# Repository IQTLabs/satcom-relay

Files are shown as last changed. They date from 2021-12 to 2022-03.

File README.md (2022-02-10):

# Satellite Communication Relay

## About

A SATCOM platform for relaying messages in remote locations.  This project provides a standard interface for messages to be relayed over a Satcom link.  Initially, this is  using the RockBlock Iridium 9603 satellite modem, but the system is designed to be able to handle any other satcom system designed for small burst data transmissions.

## System Design

### Architecture Diagram

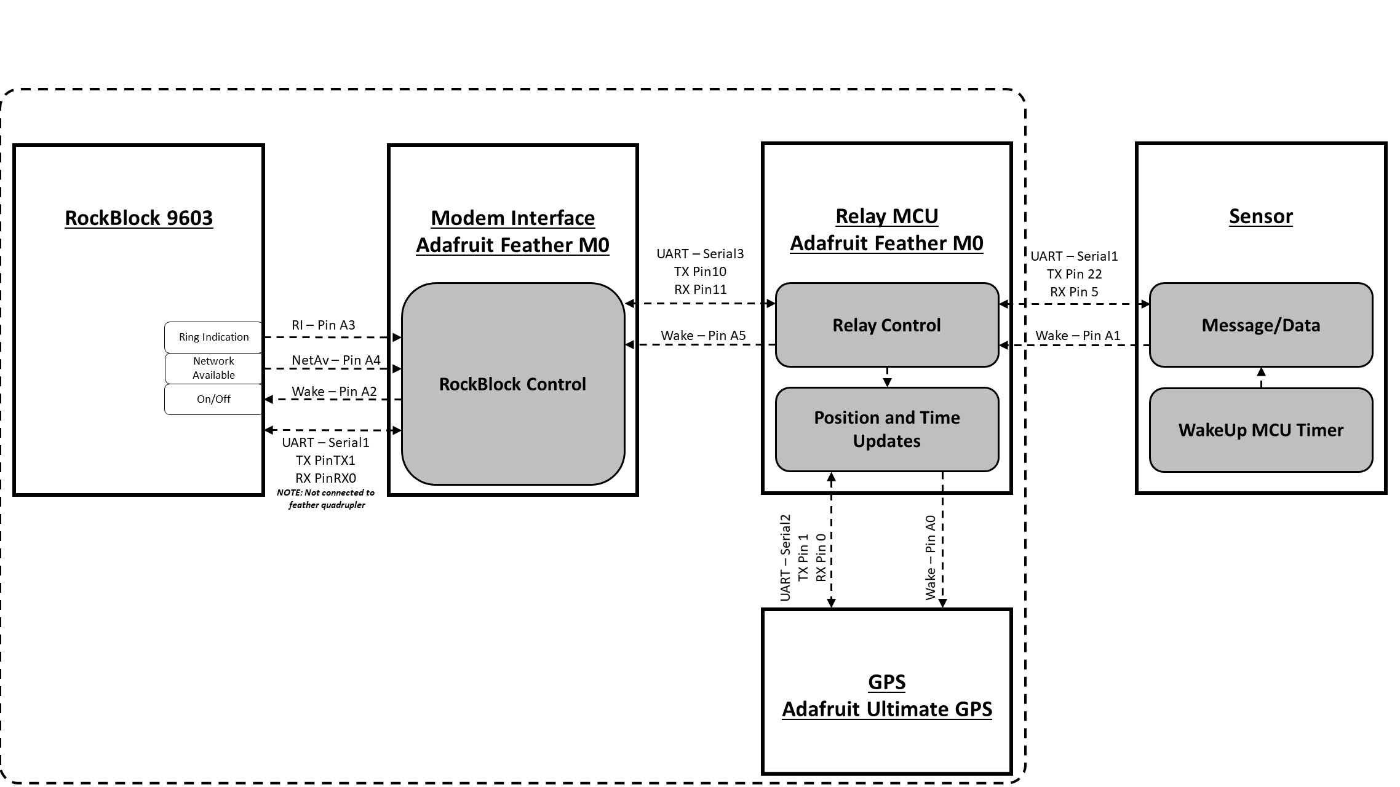
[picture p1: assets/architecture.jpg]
architecture


### Relay MCU

- Adafruit Feather M0 Basic [(diagram)](https://cdn-learn.adafruit.com/assets/assets/000/046/244/original/adafruit_products_Feather_M0_Basic_Proto_v2.2-1.png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)
    - The M0 was chosen as the Relay MCU because of its [6 SERCOM interfaces](https://learn.adafruit.com/using-atsamd21-sercom-to-add-more-spi-i2c-serial-ports/creating-a-new-serial).

### Iridium Modem Interface MCU
- Adafruit Feather M0 Adalogger [(diagram)](https://cdn-learn.adafruit.com/assets/assets/000/107/293/original/adafruit_products_Adafruit_Feather_M0_Adalogger_Pinout.png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)
- Firmware: https://github.com/IQTLabs/satcom-modem-interface

### Wiring Diagram

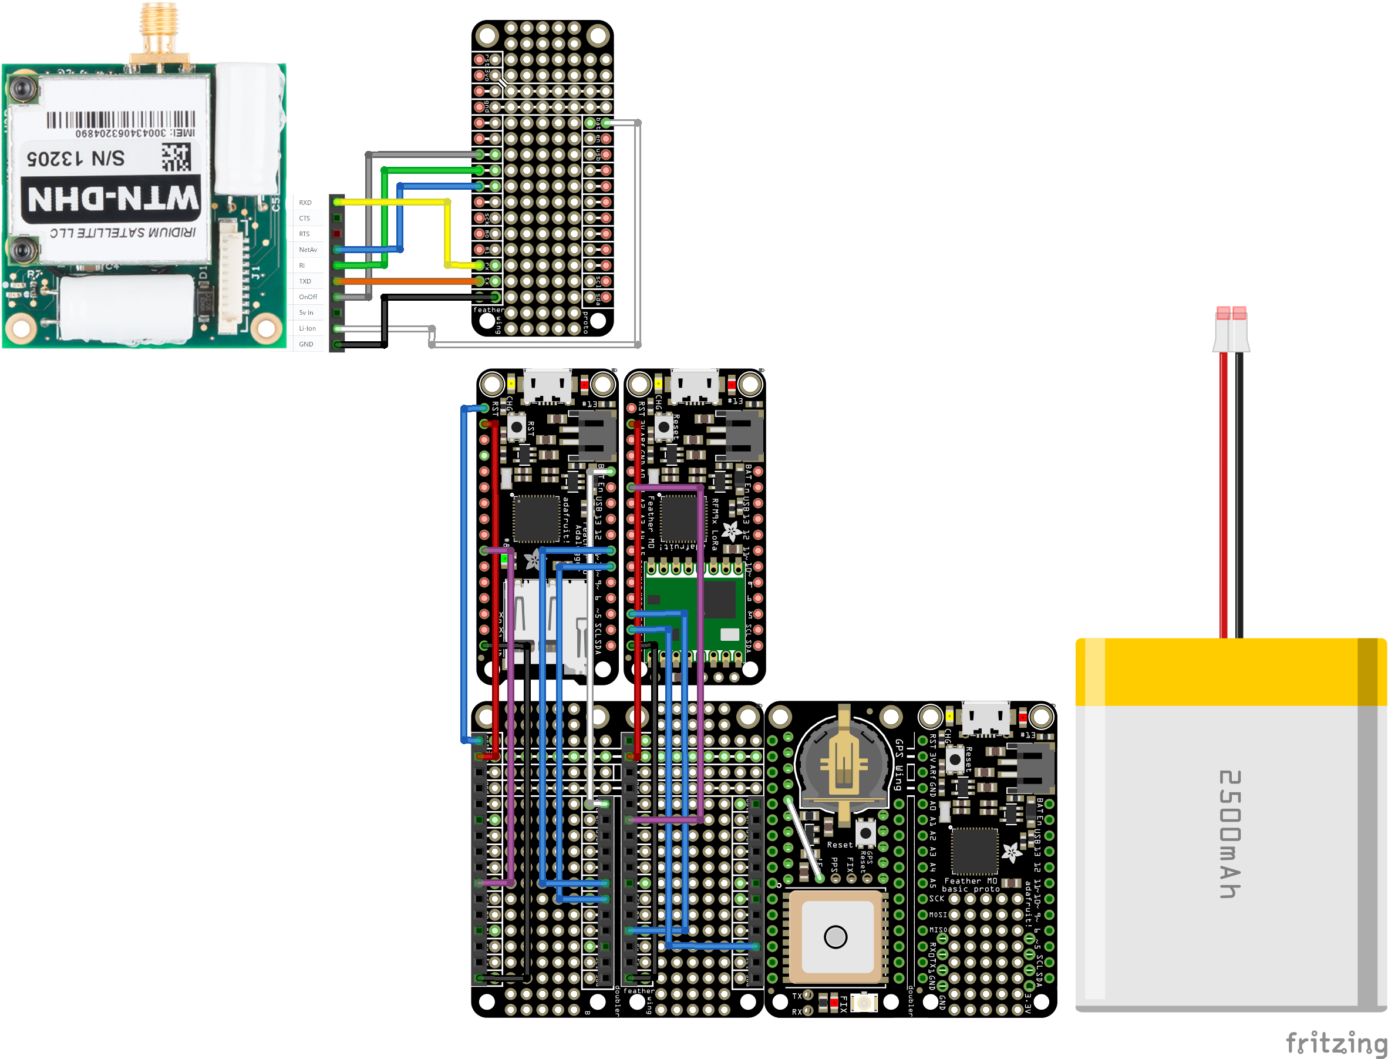
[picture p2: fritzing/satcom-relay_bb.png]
fritzing


*Note on connecting AdaLogger Feather and LoRa Feather: Only pins with indicated wires should be connected to quadrupler. All others should be removed or folded out of the way.

### Arduino Setup / Flashing

1. Install Arduinu IDE
2. Install Arduino **Adafruit M0 SAMD21** Board
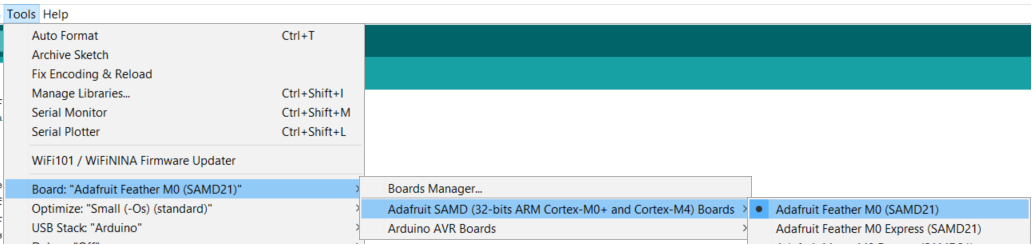
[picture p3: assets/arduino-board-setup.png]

3. Install Arduino Libraries
    - **Adafruit GPS Library** by Adafruit
    - **IridiumSBDi2c** by SparkFun Electronics [(datasheet)](https://docs.rockblock.rock7.com/docs/connectors)
    - **ArduinoJson** by Benoit Blanchon
4. Clone / download repository, open .ino file, and flash to MCU
    - Relay MCU
        - satcom-relay.ino
        - **Adafruit Feather M0**
    - Modem Interface MCU
        - satcom-modem-interface.ino*
        - **Adafruit Feather M0 AdaLogger**

### Hardware Assembly



### Bill of Materials
| Short Name | Product Name | Price | Link |
| --- | --- | ----- | ---- |
| MCU | Feather M0 Basic Proto | $19.95 | https://www.adafruit.com/product/2772 |
| GPS | Ultimate GPS FeatherWing | $24.95 | https://www.adafruit.com/product/3133 |
| SATCOM Interface MCU | Feather M0 Adalogger | $19.95 | https://www.adafruit.com/product/2796 |
| Stacking Headers | Stacking Headers for Feather - 12-pin and 16-pin female headers | $1.25 | https://www.adafruit.com/product/2830 |
| SATCOM Modem | RockBlock 9603N | $249.95 | https://www.adafruit.com/product/4521 |
| PCB-A | Feather Quad Side-By-Side | $9.95 | https://www.adafruit.com/product/4254 |
| PCB-B | RockBlock to Feather Adapter | --- | [Design Files](./electrical/IridiumPCB) |
| Battery | Lithium Ion Battery Pack - 3.7V 6600mAh | $24.50 |  https://www.adafruit.com/product/353 |
| GPS Battery | CR1220 Coin Cell Battery | $0.95 | https://www.adafruit.com/product/380 |
| Sensor FeatherWing | FeatherWing Proto | $4.95 | https://www.adafruit.com/product/2884 |
| Micro SD Card | Micro SD Card | --- | --- |
| Dry Box Case | SE 56 Micro | $26.00 | https://evergreencases.com/ |
| Dry Box Screws | Rounded Head Thread-Forming Screws for Brittle Plastic, 18-8 Stainless Steel, Number 4 Size, 3/8" Long | --- | https://www.mcmaster.com/97349A100/ |
| 3D Printed Case Chassis | SE56-chassis.STL | --- | [SE56-chassis.STL](./hardware/SE56-chassis.STL) |
| Threaded Inserts | Tapered Heat-Set Inserts for Plastic Brass, M2.5 x 0.45 mm Thread Size, 3.4 mm Installed Length | --- | https://www.mcmaster.com/94180A321/ |
| Mounting Screws | Button Head Hex Drive Screw Passivated 18-8 Stainless Steel, M2.5 x 0.45 mm Thread, 4mm Long | --- | https://www.mcmaster.com/92095A456/ |
| Mounting Screws | Button Head Hex Drive Screw 18-8 Stainless Steel, M2.5 x 0.45 Thread Size, 20mm Long | --- | https://www.mcmaster.com/92095A115/ |

## Operations

The M0 uses SERCOM2 (RX pin 5 and TX pin 22) to listen for JSON messages from other devices. These messages then get additional keys added (`uptime_ms` and `version`) and then logged out the console.

The M0 will automatically go to sleep after `AWAKE_INTERVAL` (1 minute) if the interrupt pin (A1) hasn't been toggled. Every time the interrupt pin is toggled the `awakeTimer` is reset and the count towards `AWAKE_INTERVAL` starts over. When in sleep mode, toggling the interrupt pin will wake up the M0 again.

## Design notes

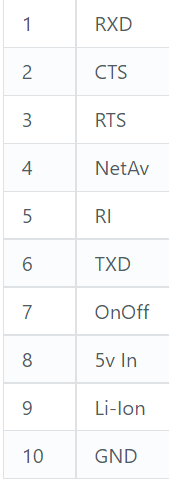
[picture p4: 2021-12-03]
fritzing/rockblock-9603-pinout.png

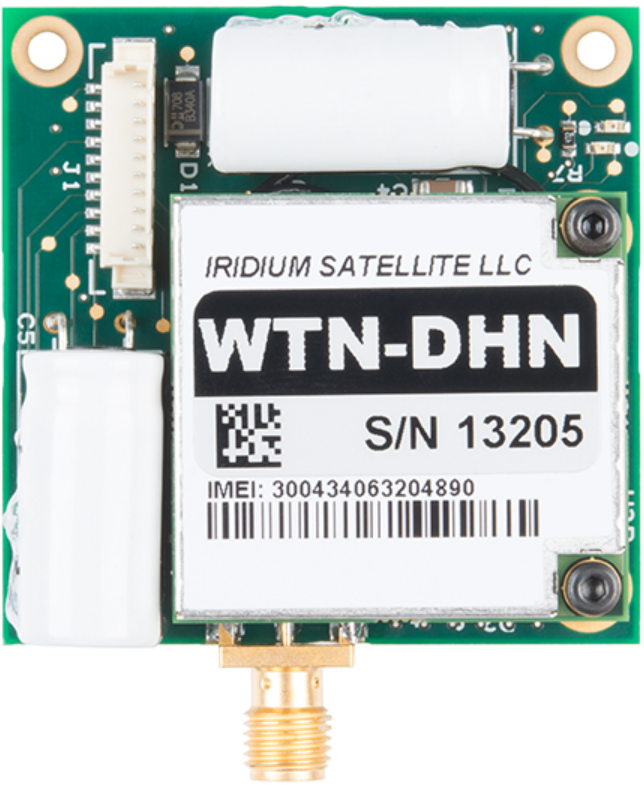
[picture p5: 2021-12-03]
fritzing/rockblock-9603.png

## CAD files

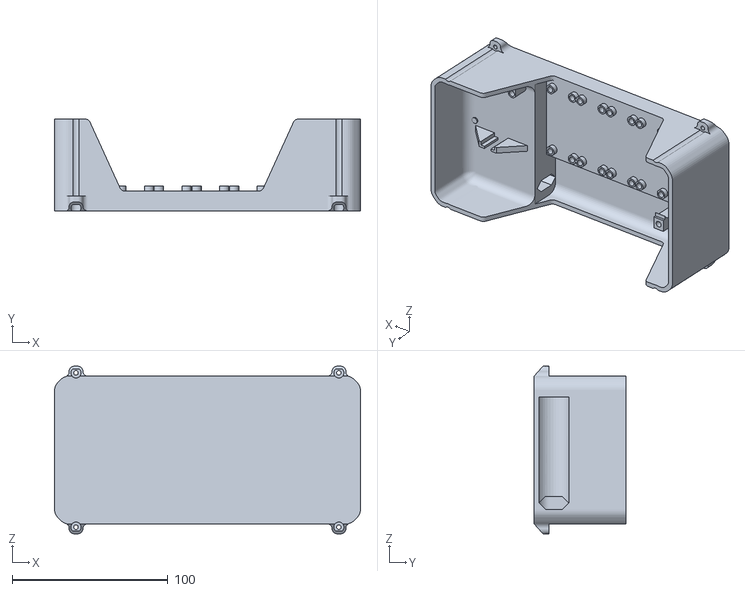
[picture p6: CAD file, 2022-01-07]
hardware/SE56-chassis.STL
196.5 x 58.9 x 107.6

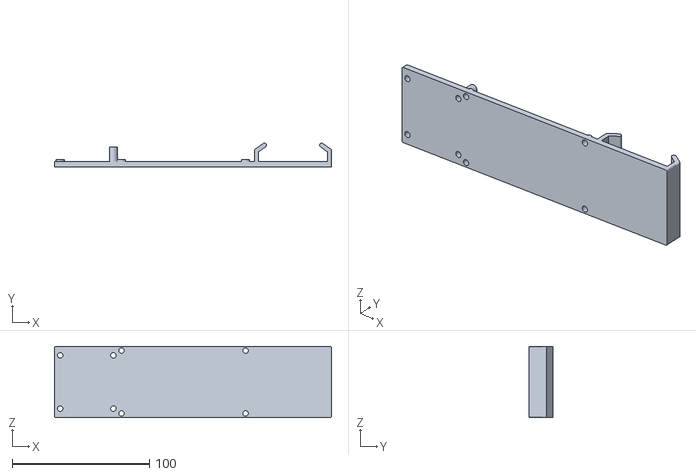
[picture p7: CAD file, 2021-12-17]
hardware/protoplate-quad-2500mah.STL
201.5 x 17.3 x 52.0

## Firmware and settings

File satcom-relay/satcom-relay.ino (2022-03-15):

#include <ArduinoJson.h>
#include "satcom-relay.h"
#include "timediff.h"
#include "sleepmanager.h"
#include "iridium-modem.h"
#include "sensor-manager.h"

SATCOMRelay relay;

const char fwVersion[] = "2";
const int jsonBufferSize = 256;
const byte wakeupRetries = 30;
DynamicJsonDocument doc(jsonBufferSize);

#define interruptPin 15
#define AWAKE_INTERVAL (60 * 1000)
SleepManager sleepmanager(digitalPinToInterrupt(interruptPin), AWAKE_INTERVAL);

volatile uint32_t gpsTimer, gpsBootTimer, testModePrintTimer, batteryCheckTimer, ledBlinkTimer = 2000000000L; // Make all of these times far in the past by setting them near the middle of the millis() range so they are checked promptly
bool iridium_wakeup_state = false;
bool hasFixOnBoot = false;
bool gpsBooted = false;

Uart IridiumInterfaceSerial(&sercom1, IRIDIUM_INTERFACE_RX_PIN, IRIDIUM_INTERFACE_TX_PIN, IRIDIUM_INTERFACE_RX_PAD, IRIDIUM_INTERFACE_TX_PAD);
Uart SensorSerial(&sercom2, SENSOR_RX_PIN, SENSOR_TX_PIN, SENSOR_RX_PAD, SENSOR_TX_PAD);

void SERCOM1_Handler()
{
  IridiumInterfaceSerial.IrqHandler();
}

void SERCOM2_Handler()
{
  SensorSerial.IrqHandler();
}

IridiumModem modem;
SensorSerialManager ssm(&SensorSerial, &doc);

void setup() {
  pinMode(LED_BUILTIN, OUTPUT);
  Serial.begin(115200);
  SensorSerial.begin(57600);
  modem.begin(&IridiumInterfaceSerial, IRIDIUM_INTERFACE_WAKEUP_PIN, IRIDIUM_INTERFACE_RX_PIN, IRIDIUM_INTERFACE_TX_PIN);

  // Assign SENSOR pins SERCOM functionality
  pinPeripheral(SENSOR_RX_PIN, PIO_SERCOM);
  pinPeripheral(SENSOR_TX_PIN, PIO_SERCOM);

  relay.gps.initGPS(Serial1);
}

void loop() {
  msgCheck();
  // wait for a warm fix on boot
  if (hasFixOnBoot) {
    relay.gps.gpsStandby();
    gpsBooted = true;
  } else if (!hasFixOnBoot && !timeExpired(&gpsBootTimer, GPS_BOOT_TIMEOUT, true)) {
    hasFixOnBoot = gpsCheck(true);
  } else {
    gpsCheck(false);
    gpsBooted = true;
  }
  batteryCheck();
  sleepCheck();
  ledBlinkCheck();
  modem.check();

  #if TEST_MODE // print the state of the relay
  if (timeExpired(&testModePrintTimer, TEST_MODE_PRINT_INTERVAL, true)) {
    relay.print();
    Serial.println();
  }
  #endif
}

void msgCheck() {
  if (!ssm.poll()) {
    return;
  }
  bool isHeartBeat = false;
  if (ssm.parse(&isHeartBeat)) {
    if (isHeartBeat) {
      for (byte j = 0; j < wakeupRetries; ++j) {
        if (gpsCheck(true)) {
          break;
        }
        delay(1000);
      }
    }
    doc["u_ms"] = millis();
    doc["v"] = fwVersion;
    doc["lat"] = relay.gps.getLastFixLatitude();
    doc["lon"] = relay.gps.getLastFixLongitude();
    doc["bat"] = relay.getBatteryVoltage();
    modem.wakeup();
    modem.sendJSON(doc);
    serializeJson(doc, Serial);
    Serial.println();
    ssm.resetBuffer();
  }
}

// Periodically check the GPS for current position
bool gpsCheck(bool forceCheck) {
  bool hasFix = false;
  relay.gps.readGPSSerial(); // we need to keep reading in main loop to keep GPS serial buffer clear
  if (forceCheck || timeExpired(&gpsTimer, GPS_WAKEUP_INTERVAL, false)) {
    relay.gps.gpsWakeup(); // wake up the GPS until we get a fix or timeout
    hasFix = relay.gps.gpsHasFix();
    if (hasFix || timeExpired(&gpsTimer, GPS_WAKEUP_INTERVAL+GPS_LOCK_TIMEOUT, true)) {
      relay.gps.gpsStandby();
      #if DEBUG_MODE
      Serial.print("DEBUG: ");if (relay.gps.gpsHasFix()) {Serial.println("GOT GPS FIX");} else {Serial.println("GPS FIX TIMEOUT");}
      #endif
    }
  }
  return hasFix;
}

// Periodically check the battery level and update member variable
void batteryCheck() {
  if (timeExpired(&batteryCheckTimer, BATTERY_CHECK_INTERVAL, true)) {
    relay.checkBatteryVoltage();
  }
}

void sleepCheck() {
  if ((hasFixOnBoot || gpsBooted) && sleepmanager.SleepTime()) {
    // set pin mode to low
    digitalWrite(LED_BUILTIN, LOW);
    Serial.println("sleeping as timed out");
    // make sure GPS also goes to sleep
    relay.gps.gpsStandby();
    delay(500);
    #ifdef WINDOWS_DEV
    USBDevice.detach();
    #else
    USBDevice.standby();
    #endif
    sleepmanager.WFI();
    #ifdef WINDOWS_DEV
    USBDevice.attach();
    #endif
    delay(1000);
    Serial.println("wake due to interrupt");
    Serial.println();
    // request repeat of last message.
    // commenting out as it seems to have enough time to wake
    // SensorSerial.println();
    // toggle output of built-in LED pin
    digitalWrite(LED_BUILTIN, HIGH);
  }
}

// Blink to show the Relay MCU is awake
void ledBlinkCheck() {
  if (timeExpired(&ledBlinkTimer, LED_BLINK_TIMER, true)) {
    digitalWrite(LED_BUILTIN, !digitalRead(LED_BUILTIN));
  }
}

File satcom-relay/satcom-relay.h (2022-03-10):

#ifndef SATCOMRelay_H
#define SATCOMRelay_H

#include <Arduino.h>
#include "gps.h"

#define WINDOWS_DEV

#define TEST_MODE true
#define TEST_MODE_PRINT_INTERVAL 2000 // use for testing. prints relay status to Serial

#define DEBUG_MODE false // print lots of debugging messages

#define VBATPIN 9 //A7
#define BATTERY_CHECK_INTERVAL 10000

#define LED_BLINK_TIMER 500
// https://learn.adafruit.com/using-atsamd21-sercom-to-add-more-spi-i2c-serial-ports
#define IRIDIUM_INTERFACE_WAKEUP_PIN 19
#define IRIDIUM_INTERFACE_RX_PIN 10
#define IRIDIUM_INTERFACE_TX_PIN 11
#define IRIDIUM_INTERFACE_RX_PAD SERCOM_RX_PAD_2
#define IRIDIUM_INTERFACE_TX_PAD UART_TX_PAD_0

#define SENSOR_RX_PIN 5
#define SENSOR_TX_PIN 22
#define SENSOR_RX_PAD SERCOM_RX_PAD_3
#define SENSOR_TX_PAD UART_TX_PAD_0

class SATCOMRelay {

private:
  float battery = -1;

public:
  GPS gps;

  SATCOMRelay();
  void print();
  void checkBatteryVoltage();
  float getBatteryVoltage();
};

#endif

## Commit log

2021-12-01 document arduino libs
2021-12-03 first pass at relay app
2021-12-03 fritzing diagram
    [satcom-relay.fzz]
2021-12-03 correct wiring diagram
    [satcom-relay.fzz]
2021-12-05 fritzing fix
    [satcom-relay.fzz]
2021-12-05 switch to object orient arduino sketch
2021-12-05 GPS standby mode using EN pin
2021-12-05 add battery voltage check
2021-12-06 update GPS EN pin
    [satcom-relay.fzz]
2021-12-07 update wiring diagram
    [satcom-relay.fzz]
2021-12-07 add sleep interrupt functionality
2021-12-08 wake timer.
2021-12-10 update rockblock wiring
    [satcom-relay.fzz]
2021-12-14 blink LED when awake. LED off when sleeping.
2021-12-14 Add PCB Files
2021-12-14 Update Fritzing with new PCB
    [satcom-relay.fzz]
2021-12-14 Fritzing Update
    [satcom-relay.fzz]
2021-12-15 Update PCB to fix bug
    Wiring the battery to Lion pin on the RockBlock, accidentally wired it to 5V
2021-12-15 relay<-->modem sercom pin10/11 example
2021-12-15 fritzing updates
    [satcom-relay.fzz]
2021-12-15 Add RF/LoRa Module to diagram
    [satcom-relay.fzz]
2021-12-15 Add Iridium interface MCU interrupt to diagram
    [satcom-relay.fzz]
2021-12-17 add 3d printed bench test fixture
    [protoplate-quad-2500mah.STL]
2021-12-17 relay simulator to test iridium interface
2021-12-17 change relay simulator to sercom1
2021-12-17 change relay<-->iridium to sercom1
2021-12-18 relay <--> interface work
2021-12-19 Update Fritzing Colors for RockBlock Wire
    [satcom-relay.fzz]
2021-12-20 add coin battery; use usbstandby; remove unused var
2021-12-20 iridum pin state.
2021-12-20 couple fixes
2021-12-21 update fritzing
    [satcom-relay.fzz]
2021-12-23 BOM updates
2021-12-24 cast to avoid zc.
    [satcom-relay.ino]
2022-01-04 swap GPS and Sensor serial pins
    [gps.cpp, satcom-relay.h, satcom-relay.ino]
2022-01-06 corner case for gps
2022-01-07 readme updates + assembly animation
    [SE56-chassis.STL]
2022-01-07 fritzing update for GPS En wire
    [satcom-relay.fzz]
2022-01-12 wire reset pin from adalogger to quadrupler
    [satcom-relay.fzz]
2022-01-28 remove old JSON keys that are no longer used
    [satcom-relay.ino]
2022-02-10 add arduino flashing instructions
2022-03-10 Move iridium modem to own file, sensor serial to own file/class, add JSON tests.
2022-03-11 fix cppcheck, simulate sensor uart for testing.
    [gps.cpp, iridium-modem.h, test_satcom_relay.ino]
